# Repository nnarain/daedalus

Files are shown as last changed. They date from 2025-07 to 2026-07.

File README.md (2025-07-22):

# Daedalus





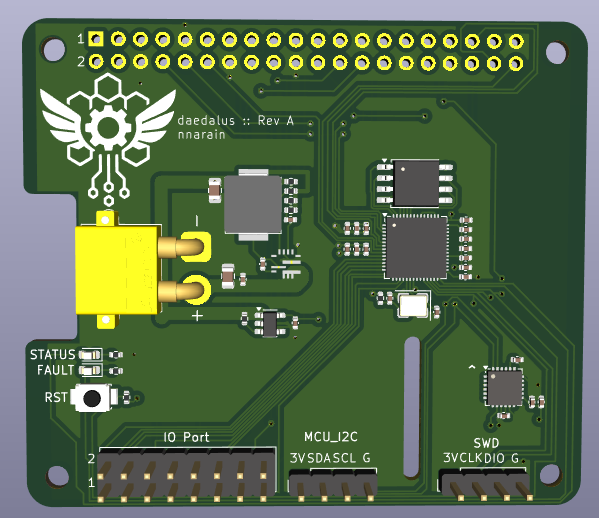
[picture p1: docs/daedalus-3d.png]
Image not found


Daedalus is a Raspberry Pi add-on that aim's to supply the necessary components for common robotics applications such as power distribution, IO, sensors and software defined embedded logic.

The current revision (Rev A) is a Proof-of-concept and contains the following:

- A switch mode power supply taking an input of 7V - 25V (2S to 6S LiPo battery) and and output of 5V @ 6A continuous
- A 3.3V linear regulator
- On board RP2040 co-processor
- MPU-6050 IMU
- 16 GPIO (8x Pi + 8x MCU)

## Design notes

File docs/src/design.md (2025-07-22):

# Design

Daedalus is designed as a comprehensive Raspberry Pi add-on board for robotics applications.

## Power Supply

The board features a switch mode power supply that can accept input voltages from 7V to 25V (suitable for 2S to 6S LiPo batteries) and provides a stable 5V output at up to 6A continuous current.

Additionally, a 3.3V linear regulator provides power for low-power components and ensures clean power for sensitive analog circuits.

## Microcontroller

An onboard RP2040 co-processor provides additional GPIO and processing capabilities, complementing the Raspberry Pi's capabilities.

## Sensors

The board includes an MPU-6050 IMU (Inertial Measurement Unit) providing:
- 3-axis gyroscope
- 3-axis accelerometer  
- Temperature sensor

## GPIO

The board provides 16 GPIO pins total:
- 8 GPIO pins connected to the Raspberry Pi
- 8 GPIO pins connected to the RP2040 MCU

This allows for flexible interfacing with external sensors, actuators, and other peripherals commonly used in robotics applications.

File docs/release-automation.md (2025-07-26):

# Release Automation

This document describes the automated release generation process for the Daedalus project.

## Features

The release automation provides the following enhancements:

- **Automated Changelog**: Generates changelog content from git commit history between tags
- **3D PCB Render**: Automatically attaches the 3D render of the PCB to releases
- **Rich Release Descriptions**: Creates detailed release descriptions with embedded images
- **Asset Organization**: Properly organizes and names release assets

## How It Works

### Changelog Generation

The `scripts/generate_changelog.py` script:
- Extracts commits between the current and previous git tags
- Groups commits by type (features, fixes, other changes)
- Generates markdown-formatted changelog content
- Handles edge cases like first releases without previous tags

### 3D Render Attachment

The workflow:
- Uses the existing KiBot `render3d` output configuration
- Extracts the 3D render PNG from `output/renders/daedalus.png`
- Renames it to `daedalus-3d-render.png` for release attachment
- Embeds the image in the release description

### Release Body Format

Each release includes:
- Release title with version
- Embedded 3D PCB render image
- Generated changelog content
- Downloads section describing each asset

## Usage

The automation runs automatically when:
- A git tag is pushed to the repository
- The workflow is manually triggered via `workflow_dispatch`

### Manual Testing

Run the test suite to validate components:

```bash
# Run comprehensive tests
./scripts/test_comprehensive.sh

# Test changelog generation specifically
python3 scripts/generate_changelog.py --tag HEAD
```

## File Structure

```
scripts/
├── generate_changelog.py      # Main changelog generation script
├── test_comprehensive.sh      # Full test suite
└── test_release.sh           # Basic component tests

.github/workflows/
└── release.yml               # Enhanced workflow with automation
```

## Customization

### Changelog Format

Edit `scripts/generate_changelog.py` to modify:
- Commit grouping logic
- Markdown formatting
- Section headers

### Release Description

Edit `.github/workflows/release.yml` to customize:
- Release body template
- Asset descriptions
- Image placement

## Troubleshooting

- **No changelog generated**: Ensure the repository has commit history and proper git tag structure
- **Missing 3D render**: Verify the KiBot configuration generates output in `renders/daedalus.png`
- **Workflow fails**: Check that all required files exist and scripts have proper permissions

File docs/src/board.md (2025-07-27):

# Board

## Board Renders

Top render

Bottom render

3D render

## Schematic

Schematic

You can also download the [schematic PDF]({{#find schematic}}).

## Interactive BOM

Check out the [interactive BOM]({{#find ibom}}) for component placement and part information.

## Manufacturing Files

Download [JLCPCB fabrication files]({{#find jlcpcb-files}}) for PCB manufacturing.

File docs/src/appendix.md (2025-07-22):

# Appendix

## Revision History

### Rev A (Proof of Concept)
The current revision is a proof-of-concept that demonstrates the core functionality of the Daedalus add-on board.

## Resources

- [Project Repository](https://github.com/nnarain/daedalus)
- [KiCAD Project Files](https://github.com/nnarain/daedalus)

## License

This project is open source hardware. Please check the repository for specific license details.

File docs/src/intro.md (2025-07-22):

image not found!

Daedalus is a Raspberry Pi add-on that aims to supply the necessary components for common robotics applications such as power distribution, IO, sensors and software defined embedded logic.

Features:

* Switch mode power supply (7V - 25V input, 5V @ 6A output)
* 3.3V linear regulator
* On board RP2040 co-processor
* MPU-6050 IMU
* 16 GPIO (8x Pi + 8x MCU)

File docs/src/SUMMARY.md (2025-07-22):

# Summary

- [Introduction](./intro.md)
- [Design](./design.md)
- [Board](./board.md)
- [Appendix](./appendix.md)

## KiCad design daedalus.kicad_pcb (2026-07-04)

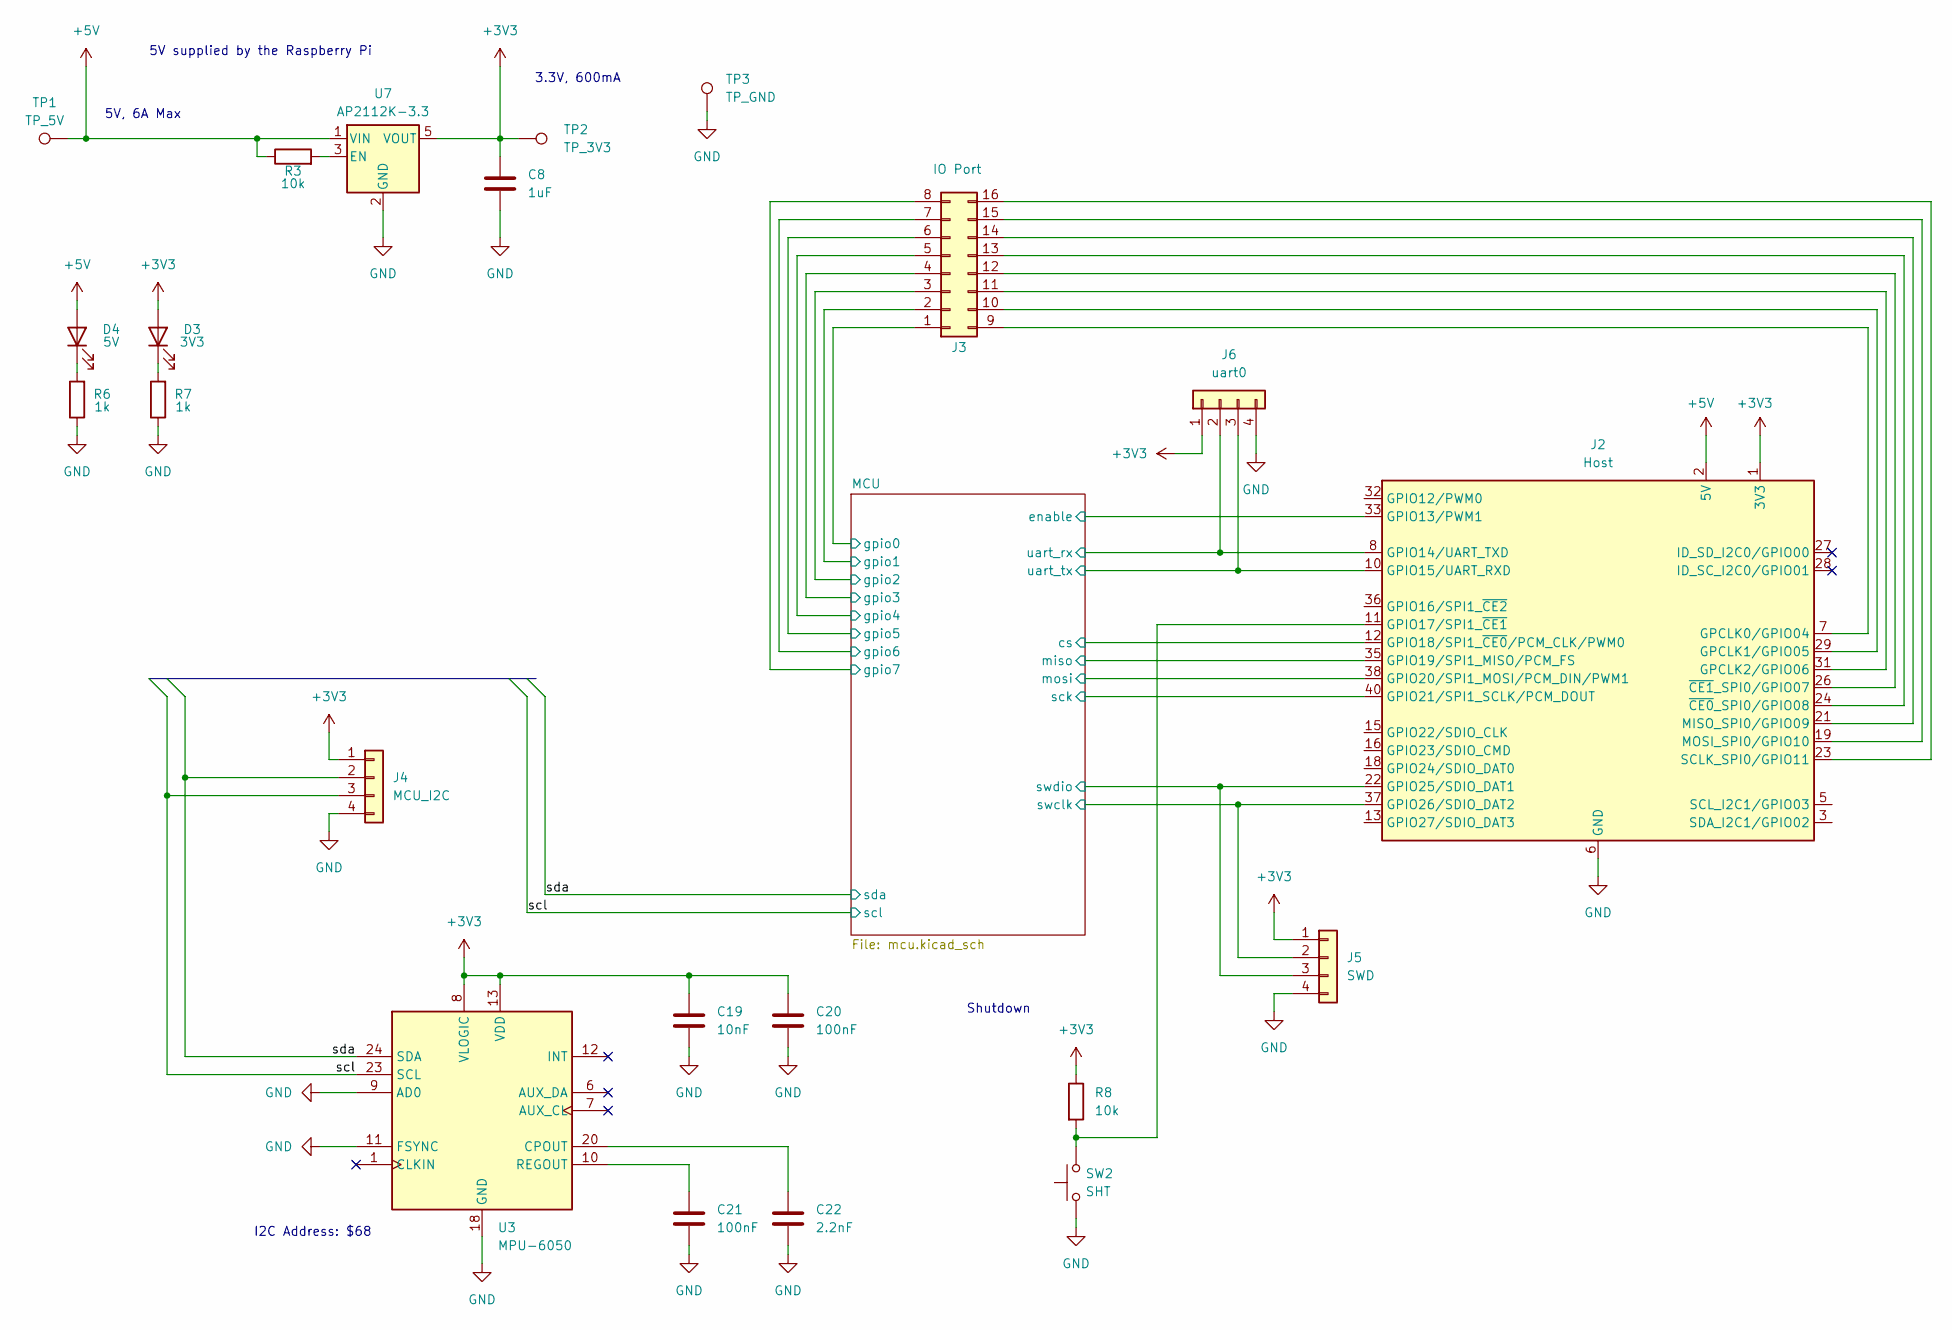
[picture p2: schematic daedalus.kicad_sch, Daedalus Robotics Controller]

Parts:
C8: 1uF; C_0402_1005Metric; LCSC C52923
C19: 10nF; C_0402_1005Metric; LCSC C15195
C20, C21: 100nF; C_0402_1005Metric; LCSC C307331
C22: 2.2nF; C_0402_1005Metric; LCSC C1531
D3: 3V3; LED_0603_1608Metric; LCSC C72043
D4: 5V; LED_0603_1608Metric; LCSC C72043
J2: Host; Raspberry_Pi_HAT_2_3_4
J3: IO Port; PinHeader_2x08_P2.54mm_Vertical
J4: MCU_I2C; PinHeader_1x04_P2.54mm_Vertical
J5: SWD; PinHeader_1x04_P2.54mm_Vertical
J6: uart0; PinHeader_1x04_P2.54mm_Vertical
R3, R8: 10k; R_0402_1005Metric; LCSC C25744
R6, R7: 1k; R_0402_1005Metric; LCSC C25543
SW2: SHT; TS-1088-AR02016; LCSC C720477
TP1: TP_5V; TestPoint_Pad_2.0x2.0mm
TP2: TP_3V3; TestPoint_Pad_2.0x2.0mm
TP3: TP_GND; TestPoint_Pad_2.0x2.0mm
U3: MPU-6050; InvenSense_QFN-24_4x4mm_P0.5mm; LCSC C24112
U7: AP2112K-3.3; SOT-23-5; LCSC C51118

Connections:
+3V3: C8.1, C19.1, C20.1, D3.2 (A), J2.1 (3V3), J2.17 (3V3), J4.1, J5.1, J6.1, R8.1, TP2.1, U3.8 (VLOGIC), U3.13 (VDD), U7.5 (VOUT); also elsewhere on the board
+5V: D4.2 (A), J2.2 (5V), J2.4 (5V), R3.1, TP1.1, U7.1 (VIN); also elsewhere on the board
/MCU/cs: J2.12 (GPIO18/SPI1_~CE0/PCM_CLK/PWM0); also elsewhere on the board
/MCU/gpio0: J3.1; also elsewhere on the board
/MCU/gpio1: J3.2; also elsewhere on the board
/MCU/gpio2: J3.3; also elsewhere on the board
/MCU/gpio3: J3.4; also elsewhere on the board
/MCU/gpio4: J3.5; also elsewhere on the board
/MCU/gpio5: J3.6; also elsewhere on the board
/MCU/gpio6: J3.7; also elsewhere on the board
/MCU/gpio7: J3.8; also elsewhere on the board
/MCU/miso: J2.35 (GPIO19/SPI1_MISO/PCM_FS); also elsewhere on the board
/MCU/mosi: J2.38 (GPIO20/SPI1_MOSI/PCM_DIN/PWM1); also elsewhere on the board
/MCU/run: J2.33 (GPIO13/PWM1); also elsewhere on the board
/MCU/sck: J2.40 (GPIO21/SPI1_SCLK/PCM_DOUT); also elsewhere on the board
/MCU/swclk: J2.37 (GPIO26/SDIO_DAT2), J5.2; also elsewhere on the board
/MCU/swdio: J2.22 (GPIO25/SDIO_DAT1), J5.3; also elsewhere on the board
/MCU/uart_rx: J2.8 (GPIO14/UART_TXD), J6.2; also elsewhere on the board
/MCU/uart_tx: J2.10 (GPIO15/UART_RXD), J6.3; also elsewhere on the board
/scl: J4.3, U3.23 (SCL); also elsewhere on the board
/sda: J4.2, U3.24 (SDA); also elsewhere on the board
GND: C8.2, C19.2, C20.2, C21.2, C22.2, J2.6 (GND), J2.9 (GND), J2.14 (GND), J2.20 (GND), J2.25 (GND), J2.30 (GND), J2.34 (GND), J2.39 (GND), J4.4, J5.4, J6.4, R6.1, R7.1, SW2.1, TP3.1, U3.9 (AD0), U3.11 (FSYNC), U3.18 (GND), U7.2 (GND); also elsewhere on the board
unnamed: D3.1 (K), R7.2
unnamed: D4.1 (K), R6.2
unnamed: J2.7 (GPCLK0/GPIO04), J3.9
unnamed: J2.29 (GPCLK1/GPIO05), J3.10
unnamed: J2.31 (GPCLK2/GPIO06), J3.11
unnamed: J2.11 (GPIO17/SPI1_~CE1), R8.2, SW2.2
unnamed: J2.21 (MISO_SPI0/GPIO09), J3.14
unnamed: J2.19 (MOSI_SPI0/GPIO10), J3.15
unnamed: J2.23 (SCLK_SPI0/GPIO11), J3.16
unnamed: J2.24 (~CE0_SPI0/GPIO08), J3.13
unnamed: J2.26 (~CE1_SPI0/GPIO07), J3.12
unnamed: C22.1, U3.20 (CPOUT)
unnamed: C21.1, U3.10 (REGOUT)
unnamed: R3.2, U7.3 (EN)

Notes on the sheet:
5V, 6A Max
3.3V, 600mA
Shutdown
I2C Address: $68
5V supplied by the Raspberry Pi

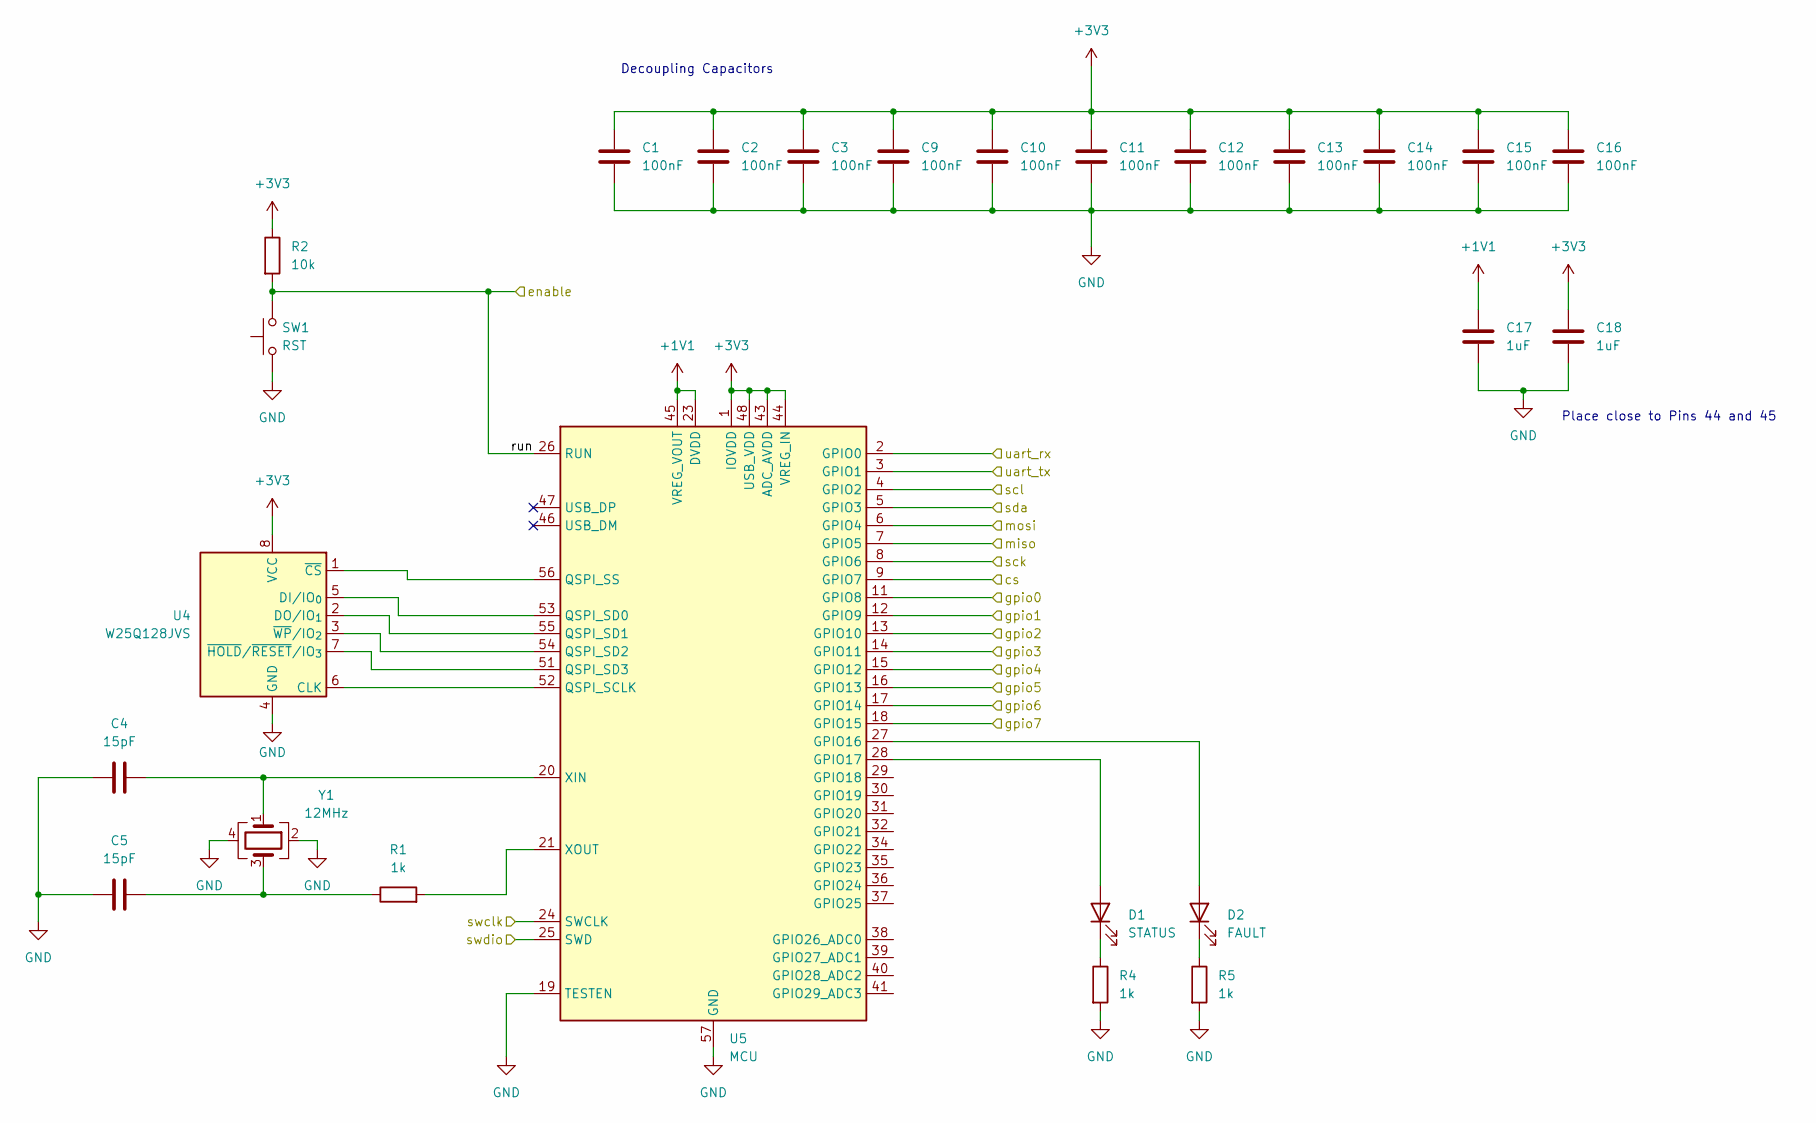
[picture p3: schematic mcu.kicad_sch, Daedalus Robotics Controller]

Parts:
C1, C2, C3, C9, C10, C11, C12, C13, C14, C15, C16: 100nF; C_0402_1005Metric; LCSC C307331
C4, C5: 15pF; C_0402_1005Metric; LCSC C326803
C17, C18: 1uF; C_0402_1005Metric; LCSC C52923
D1: STATUS; LED_0603_1608Metric; LCSC C72043
D2: FAULT; LED_0603_1608Metric; LCSC C2286
R1, R4, R5: 1k; R_0402_1005Metric; LCSC C25543
R2: 10k; R_0402_1005Metric; LCSC C25744
SW1: RST; TS-1088-AR02016; LCSC C720477
U4: W25Q128JVS; SOIC-8_5.3x5.3mm_P1.27mm; LCSC C97521
U5: MCU; QFN-56-1EP_7x7mm_P0.4mm_EP3.2x3.2mm; LCSC C2040
Y1: 12MHz; Crystal_SMD_3225-4Pin_3.2x2.5mm; LCSC C20625731

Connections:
+1V1: C17.2, U5.23 (DVDD), U5.45 (VREG_VOUT), U5.50 (DVDD)
+3V3: C1.2, C2.2, C3.2, C9.2, C10.2, C11.2, C12.2, C13.2, C14.2, C15.2, C16.2, C18.2, R2.1, U4.8 (VCC), U5.1 (IOVDD), U5.10 (IOVDD), U5.22 (IOVDD), U5.33 (IOVDD), U5.42 (IOVDD), U5.43 (ADC_AVDD), U5.44 (VREG_IN), U5.48 (USB_VDD), U5.49 (IOVDD); also elsewhere on the board
/MCU/cs: U5.9 (GPIO7); also elsewhere on the board
/MCU/gpio0: U5.11 (GPIO8); also elsewhere on the board
/MCU/gpio1: U5.12 (GPIO9); also elsewhere on the board
/MCU/gpio2: U5.13 (GPIO10); also elsewhere on the board
/MCU/gpio3: U5.14 (GPIO11); also elsewhere on the board
/MCU/gpio4: U5.15 (GPIO12); also elsewhere on the board
/MCU/gpio5: U5.16 (GPIO13); also elsewhere on the board
/MCU/gpio6: U5.17 (GPIO14); also elsewhere on the board
/MCU/gpio7: U5.18 (GPIO15); also elsewhere on the board
/MCU/miso: U5.7 (GPIO5); also elsewhere on the board
/MCU/mosi: U5.6 (GPIO4); also elsewhere on the board
/MCU/run: R2.2, SW1.2, U5.26 (RUN); also elsewhere on the board
/MCU/sck: U5.8 (GPIO6); also elsewhere on the board
/MCU/swclk: U5.24 (SWCLK); also elsewhere on the board
/MCU/swdio: U5.25 (SWD); also elsewhere on the board
/MCU/uart_rx: U5.2 (GPIO0); also elsewhere on the board
/MCU/uart_tx: U5.3 (GPIO1); also elsewhere on the board
/scl: U5.4 (GPIO2); also elsewhere on the board
/sda: U5.5 (GPIO3); also elsewhere on the board
GND: C1.1, C2.1, C3.1, C4.1, C5.2, C9.1, C10.1, C11.1, C12.1, C13.1, C14.1, C15.1, C16.1, C17.1, C18.1, R4.2, R5.2, SW1.1, U4.4 (GND), U5.19 (TESTEN), U5.57 (GND), Y1.2, Y1.4; also elsewhere on the board
unnamed: C5.1, R1.1, Y1.3
unnamed: D1.2 (A), U5.28 (GPIO17)
unnamed: D1.1 (K), R4.1
unnamed: D2.2 (A), U5.27 (GPIO16)
unnamed: D2.1 (K), R5.1
unnamed: U4.6 (CLK), U5.52 (QSPI_SCLK)
unnamed: U4.5 (DI/IO_{0}), U5.53 (QSPI_SD0)
unnamed: U4.2 (DO/IO_{1}), U5.55 (QSPI_SD1)
unnamed: U4.1 (~CS), U5.56 (QSPI_SS)
unnamed: U4.7 (~HOLD/~RESET/IO_{3}), U5.51 (QSPI_SD3)
unnamed: U4.3 (~WP/IO_{2}), U5.54 (QSPI_SD2)
unnamed: C4.2, U5.20 (XIN), Y1.1
unnamed: R1.2, U5.21 (XOUT)

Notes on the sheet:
Place close to Pins 44 and 45
Decoupling Capacitors

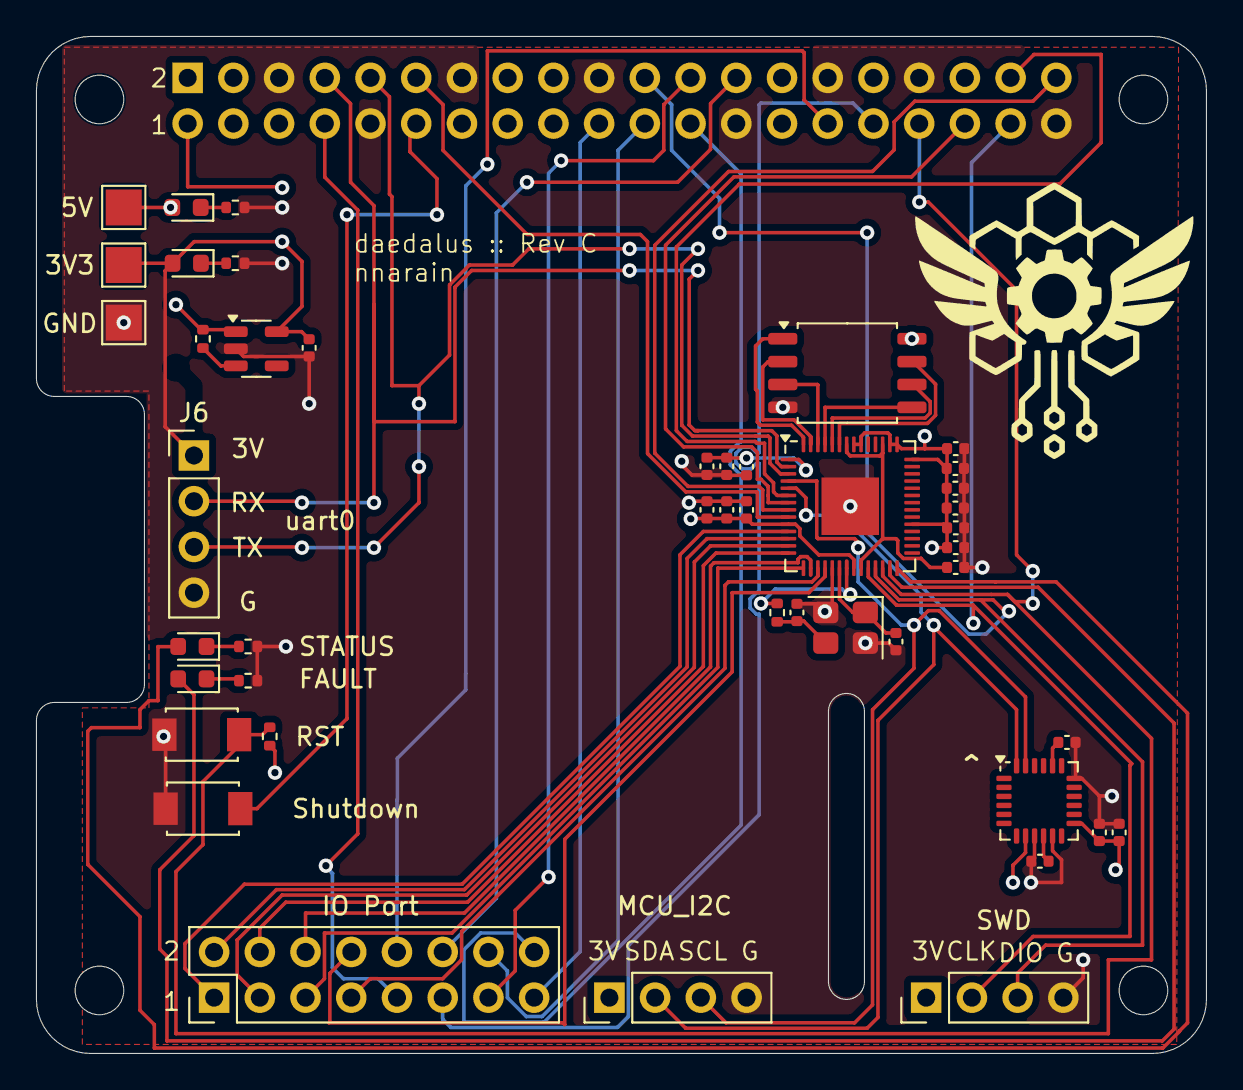
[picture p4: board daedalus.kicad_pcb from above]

Board: 4 copper layers, 65.0 x 56.5 mm, 46 parts (0 on the bottom side), 50 nets.

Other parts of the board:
3V3: TP_3V3; TestPoint_Pad_2.0x2.0mm
5V: TP_5V; TestPoint_Pad_2.0x2.0mm
GND: TP_GND; TestPoint_Pad_2.0x2.0mm

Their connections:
+3V3: 3V3.1; also elsewhere on the board
+5V: 5V.1; also elsewhere on the board
GND: GND.1; also elsewhere on the board

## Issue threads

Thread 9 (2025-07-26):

Investigate how to automate adding the Revision string to top silk layer

nnarain, 2025-07-26:
I want to automate automatically updating the revision text on the pcb to the revision string in the page settings (or some other config).

I believe this can be down with the kibot (kicad automation tool).

Scope of this issue is to find a method for doing that and documenting it. No pull request is necessary.

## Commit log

2025-07-09 Daedalus Rev A PoC
    [daedalus.kicad_pcb, daedalus.kicad_sch, mcu.kicad_sch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]
2025-07-10 added missing lcsc part number
    [daedalus.kicad_sch, mcu.kicad_sch]
2025-07-27 fix raspberry pi hat pinout
    [daedalus.kicad_pcb, daedalus.kicad_sch]
2025-07-27 Add power supply test points
    [daedalus.kicad_pcb, daedalus.kicad_sch, mcu.kicad_sch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]
2025-07-27 Switch to vertical xt30 connector
    [daedalus.kicad_pcb, daedalus.kicad_sch]
2026-06-20 update kicad version
    [daedalus.kicad_pcb, daedalus.kicad_sch, mcu.kicad_sch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]
2026-07-04 Rev C
    [daedalus.kicad_pcb, daedalus.kicad_sch, mcu.kicad_sch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]
